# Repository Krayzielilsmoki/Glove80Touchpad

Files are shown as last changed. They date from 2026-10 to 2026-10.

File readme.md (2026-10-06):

# CustomTouchpad V7 🚀

A DIY ergonomic desktop trackpad module powered by QMK & Vial on a Raspberry Pi RP2040 Pro Micro. Features a 40mm Cirque GlidePoint curved trackpad, dual rotary encoders (volume knob + smooth scroll roller), and customizable status RGB lighting.




---

## 📸 Photos & Demo Video

| Physical Build | Assembly / Internal Fit | Wiring Diagram |
| :---: | :---: | :---: |
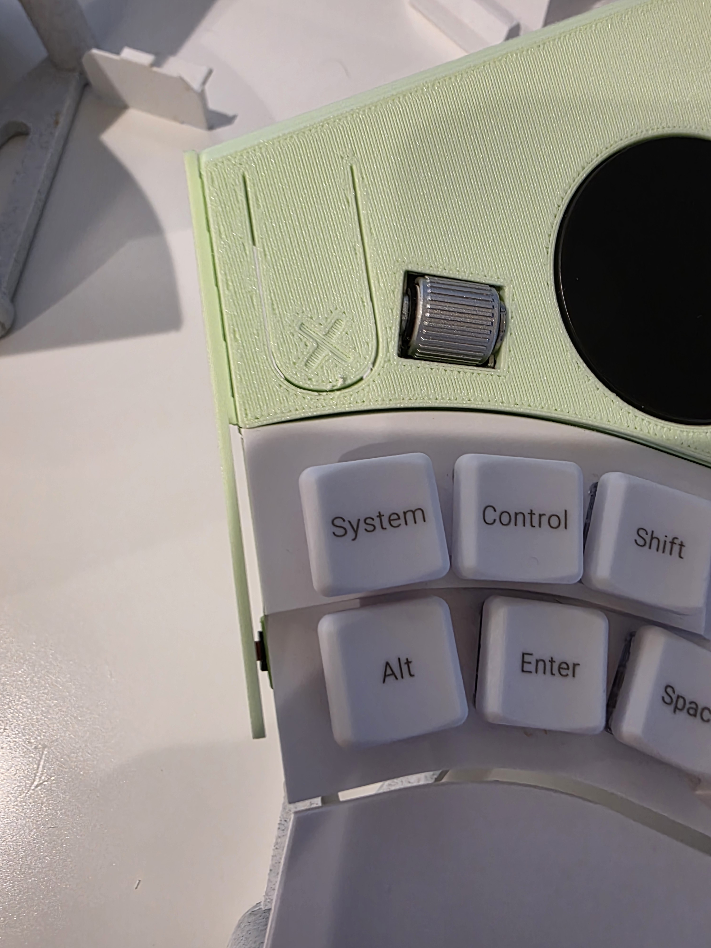
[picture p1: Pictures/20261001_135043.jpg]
Touchpad Top View
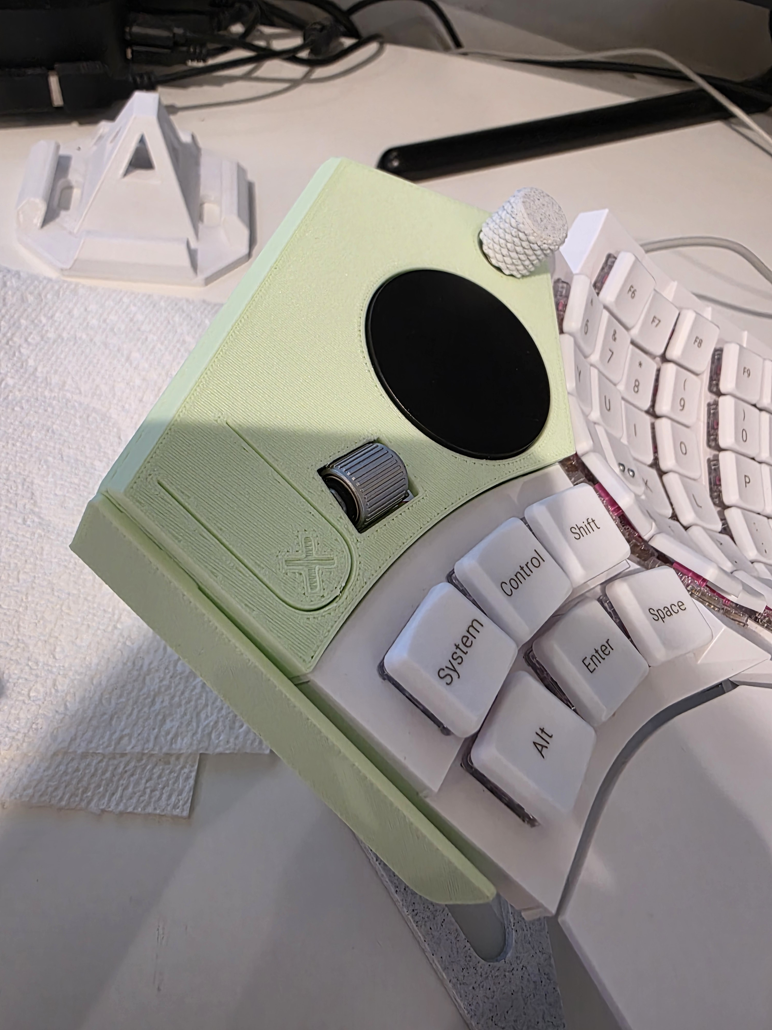
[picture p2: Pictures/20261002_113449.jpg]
Touchpad Build View
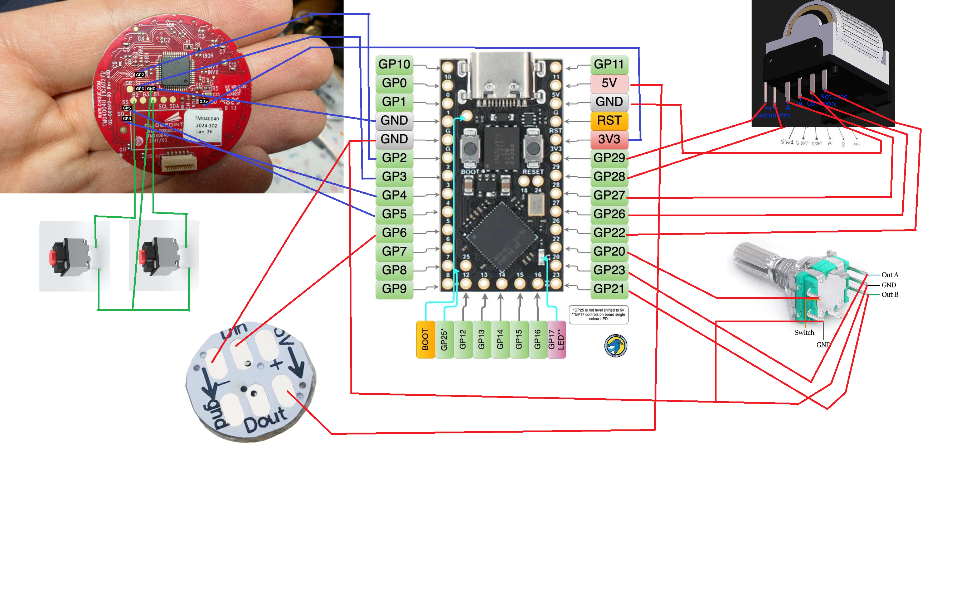
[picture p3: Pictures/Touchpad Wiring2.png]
Touchpad Wiring
|  |  |  |

🎥 **Video Demonstration**: [Watch the short showcase on YouTube](https://youtube.com/shorts/NrFE-3k1rw0)

---

## 🛠 Features

- **Cirque GlidePoint 40mm Curved Trackpad** (`TM040040-2024-303`) via SPI.
  - Dynamic Touchpad Ballistics (variable speed acceleration: slow finger movements give pixel-perfect fine control, fast flicks traverse multi-monitor setups effortlessly).
  - Sub-pixel precision accumulator to prevent pixel jitter.
  - Native Tap-to-Click, Cursor Glide (inertial flick coasting), Circular Edge Scrolling, and hardware smoothing filter.
  - Dedicated hardware mouse buttons (B1 / B2).
- **Dual Encoders**:
  - **EC11 Rotary Encoder**: Smooth audio volume wheel + push-button mute (`KC_MUTE`) on Layer 0; YouTube / media 5-second skip backward/forward + play/pause on Layer 1.
  - **Panasonic EVQWGD001 Roller Encoder**: Precision vertical / horizontal scrolling with customizable acceleration curves.
- **Multifunction Layer & Anti-Sleep Screensaver**:
  - **Layer 0 (Navigation)**: Default desktop trackpad, scroll wheel, volume knob.
  - **Layer 1 (Media / Productivity)**: Horizontal scrolling, video scrubbing (±5s seek), play/pause.
  - **Layer 2 (Anti-Sleep Screensaver / Mouse Jiggler)**: Long-press the roller button (400ms) to engage undetectable, human-like Bezier curve cursor simulation or geometric patterns (Pong bouncer, Orbit, Lissajous).
- **WS2812B RGB Status LED**: Real-time layer indicators, customizable colors, and auto-idle timeout.
- **Full Vial Integration**: Adjust sensitivity (ADC attenuation), CPI (600–1800), acceleration curves, scroll inversion, and LED colors on the fly via [Vial Web](https://vial.rocks/) without reflashing.

---

## 🧰 Bill of Materials (BOM) & Components

### Electronics & Sensors
| Component | Description | Notes |
| :--- | :--- | :--- |
| **RP2040 Pro Micro** | 3.3V RP2040 Microcontroller Board | USB Type-C recommended (sourced from AliExpress/Amazon) |
| **Cirque GlidePoint TM040040** | 40mm Circular Trackpad (Curved Overlay `TM040040-2024-303`) | SPI interface configuration (remove R1 resistor on trackpad to enable SPI mode) |
| **Panasonic EVQWGD001** | Roller Encoder | Used for primary vertical/horizontal scroll wheel (sourced from AliExpress) |
| **EC11 Rotary Encoder** | Incremental encoder with push button | Knob navigation & volume control (AliExpress/Amazon) |
| **WS2812B SMD LED** | 5050 / 3535 Addressable RGB LED | GP6 data line for status illumination |
| **JST Connectors / Pre-crimped Wires** | JST-SH (1.0mm) or JST-XH/ZH (1.25mm/1.5mm) | **Crucial for assembly**: Allows each component to unplug easily, making final fitting inside the tight enclosure possible |
| **Hookup Wire** | 28 AWG to 30 AWG silicone wire | Flexible stranded wire recommended |

> [!TIP]  
> Most electronic components (RP2040 Pro Micro, Cirque trackpad, EVQWGD001 roller, EC11 encoders, and JST connector kits) can be sourced very affordably from **AliExpress**.

### Fasteners, Inserts & Tools
| Hardware | Item / Link | Notes |
| :--- | :--- | :--- |
| **Heat-Set Threaded Inserts** | [M2.5 Heat-Set Brass Inserts (Amazon)](https://www.amazon.com/dp/B0FWCG2K1F?ref=ppx_yo2ov_dt_b_fed_asin_title&th=1) | Installed into 3D-printed standoffs for durable screw fastening (or AliExpress) |
| **Screws & Nuts Assortment** | [Mxuteuk Metric M2/M2.5/M3 Screws & Nuts Kit (Amazon)](https://www.amazon.com/dp/B0G8F366MV?ref=ppx_yo2ov_dt_b_fed_asin_title&th=1) | M2.5 socket head cap screws used for assembling top and bottom case |
| **Soldering Iron** | [80W Digital Soldering Iron Kit (Amazon)](https://www.amazon.com/dp/B08R3515SF?ref=ppx_yo2ov_dt_b_fed_asin_title&th=1) | Budget adjustable-temp iron suitable for wiring and heat-setting inserts |
| **Allen / Hex Key** | Standard small M2.5 hex wrench (included with screw kit) | Used for driving screws and reaming undersized holes |

---

## 🔌 Pinout & Wiring Diagram

Refer to the wiring schematic in [`Pictures/Touchpad Wiring2.png`](Pictures/Touchpad%20Wiring2.png):

| Component | Pin Function | RP2040 Pro Micro Pin |
| :--- | :--- | :--- |
| **Cirque Trackpad (SPI)** | SCK (Clock) | **GP2** |
| | MOSI (Data In) | **GP3** |
| | MISO (Data Out) | **GP4** |
| | CS (Chip Select) | **GP5** |
| | VCC | **3.3V** |
| | GND | **GND** |
| **Status RGB LED** | DI (Data In) | **GP6** |
| | 5V / VCC & GND | **VBUS (or 3.3V)** & **GND** |
| **Push-Button Switches** | EC11 Button Push | **GP20** (Row 0, Col 0 - Active Low) |
| | Roller Button Push | **GP29** (Row 0, Col 1 - Active Low) |
| **EC11 Rotary Encoder** | Phase A | **GP21** |
| | Phase B | **GP23** |
| | Common Pin | **GND** |
| **Panasonic EVQWGD001 Roller** | Phase A | **GP27** |
| | Phase B | **GP26** |
| | Common Pin | **GND** |

> [!NOTE]  
> The buttons are configured as direct matrix pins (`GP20`, `GP29`). Ensure switches connect between their designated GPIO pin and Ground (`COL2ROW` internal pull-up logic).

---

## 🖨️ 3D Printing & Enclosure Assembly

All enclosure STL models are located in the [`3d Print Files/`](3d%20Print%20Files/) folder:

- `top v3.stl`: Top shell housing the trackpad and encoder openings.
- `Bottom v5.stl`: Base enclosure holding the microcontroller, roller, and wiring.
- `Bottom Cover v1.stl`: Bottom access plate.
- `Clicker v3.stl`: Internal mechanical button lever / pivot.
- `keeper piece.stl`: Retaining bracket for the trackpad/roller assembly.
- `MyKnob.stl`: Custom tactile knob for the EC11 rotary encoder.

### 💡 3D Printing & Assembly Tips:
1. **Undersized Holes (Printer Tolerance)**:  
   The screw holes in the 3D printed files were intentionally modeled slightly undersized to account for different printer tolerances and shrinkage. **You can easily clear / enlarge them to the perfect diameter simply by running through them with the small Allen hex key used for the M2.5 screws.**
2. **Heat-Set Insert Installation**:  
   Set your soldering iron to ~220–250°C (if printing in PLA/PETG). Place an M2.5 brass heat-set insert over each mounting hole, gently press down with the tip of the soldering iron until the insert sinks flush with the plastic rim, then remove the iron and let it cool without disturbing it.
3. **Modular JST Connectors (Crucial for Assembly)**:  
   Because the custom enclosure is compact and tightly integrated, soldering all components directly to the RP2040 board with permanent wires makes mechanical assembly nearly impossible. **Using JST connectors (or pre-crimped JST pigtails) allows each module—trackpad, encoders, LED, and buttons—to be unplugged during installation and snapped together inside the case.**

---

## 💾 Firmware & Flashing

A pre-compiled, ready-to-flash Vial firmware binary is included right in this directory:
📁 **[`custom_touchpad_v7_vial.uf2`](custom_touchpad_v7_vial.uf2)**

### Flashing Instructions:
1. Hold down the **BOOT** button on the RP2040 Pro Micro board and plug it into your computer via USB (or double-tap **RESET**).
2. The board will appear as a removable USB storage drive named `RPI-RP2`.
3. Drag and drop [`custom_touchpad_v7_vial.uf2`](custom_touchpad_v7_vial.uf2) onto the `RPI-RP2` drive.
4. The board will automatically reboot as an HID trackpad and keyboard device.
5. Open [Vial Web App](https://vial.rocks/) or the Vial desktop application in Chrome / Edge to configure layers, sensitivity curves, and RGB settings in real time!

### Compiling from Source (Optional)
If you want to modify keymaps or compile from source within this repository:
```bash
make handwired/bojan/custom_touchpad_v7:vial
```

---

## 🎮 Default Controls & Gestures

### Layer 0: Standard Navigation (Default)
- **Trackpad**: Cursor movement (dynamic velocity acceleration).
- **Single Tap**: Left Click.
- **Top-Right / Outer Perimeter**: Circular Scroll (or roller wheel).
- **EC11 Knob Rotate**: Volume Down / Volume Up.
- **EC11 Knob Click**: Audio Mute / Unmute.
- **EVQWGD001 Roller Scroll**: Accelerated Vertical Page Scroll.
- **EVQWGD001 Roller Click**: 
  - *Short Tap*: Switch between Layer 0 and Layer 1.
  - *Hold (>= 400ms)*: Enter Layer 2 (Anti-Sleep Screensaver).

### Layer 1: Media & Productivity
- **EC11 Knob Rotate**: YouTube / Video seek 5s backward (`KC_LEFT`) / forward (`KC_RIGHT`).
- **EC11 Knob Click**: Play / Pause video (`KC_MPLY`).
- **EVQWGD001 Roller Scroll**: Horizontal scroll (`MS_WHLL` / `MS_WHLR`).
- **EVQWGD001 Roller Click**: Switch back to Layer 0.

### Layer 2: Screensaver / Anti-Sleep Mode
- **EC11 Knob Rotate**: Increase / decrease movement speed (1–10).
- **EVQWGD001 Roller Scroll**: Cycle through 4 animation patterns:
  - *Pattern 0*: Natural Human Simulator (random idle pauses & smooth Bezier curves).
  - *Pattern 1*: Pong / DVD screen bounce.
  - *Pattern 2*: Circular orbit.
  - *Pattern 3*: Lissajous figure-8.
- **Any Button Click or Trackpad Movement**: Automatically wakes and returns to Layer 0.

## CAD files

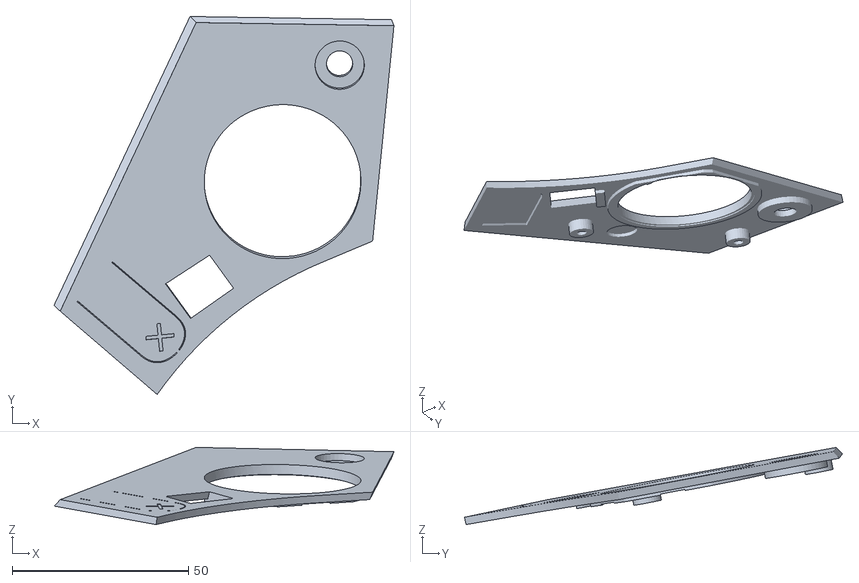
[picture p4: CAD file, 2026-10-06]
3d Print Files/top v3.stl
96.5 x 107.3 x 21.9

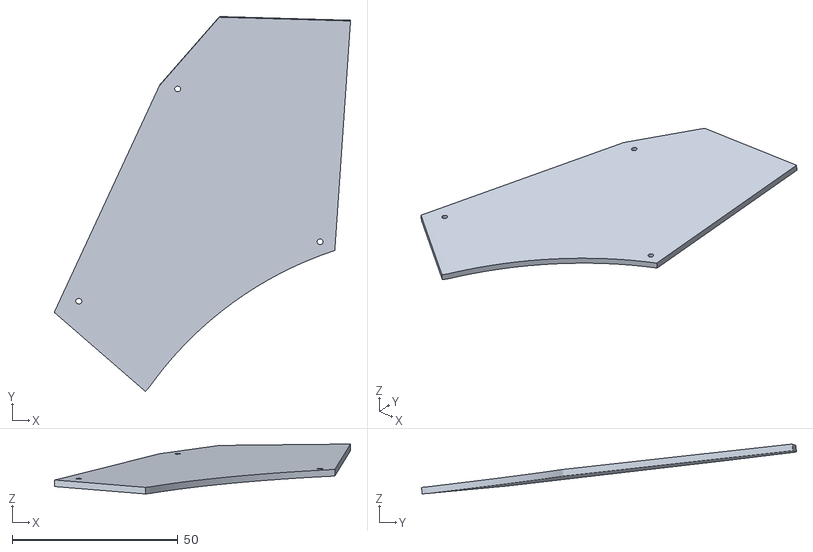
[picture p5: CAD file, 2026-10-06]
3d Print Files/Bottom Cover v1.stl
89.3 x 113.1 x 15.1

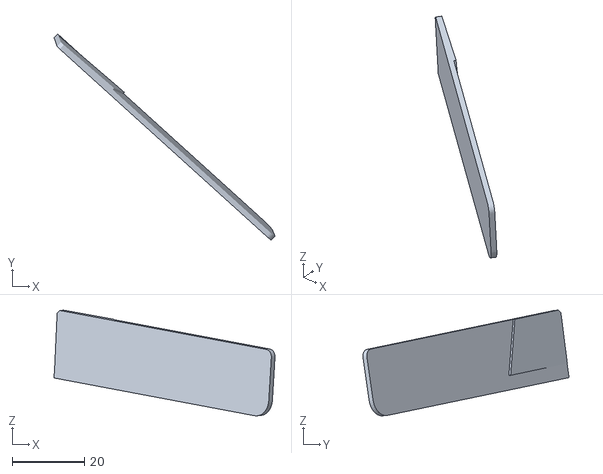
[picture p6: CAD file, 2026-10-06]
3d Print Files/Clicker v3.stl
61.2 x 57.1 x 29.3

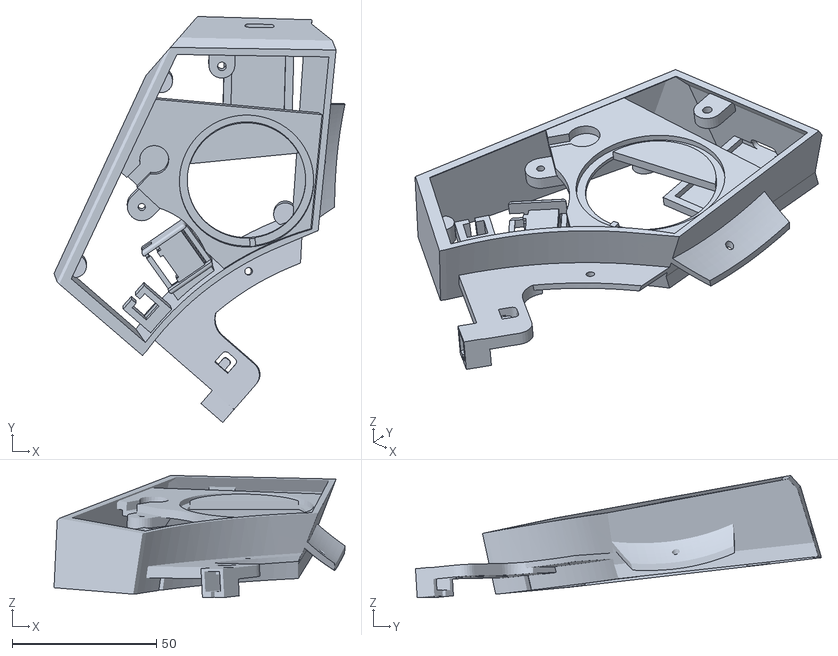
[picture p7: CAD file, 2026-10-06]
3d Print Files/Bottom v5.stl
100.8 x 140.6 x 42.3

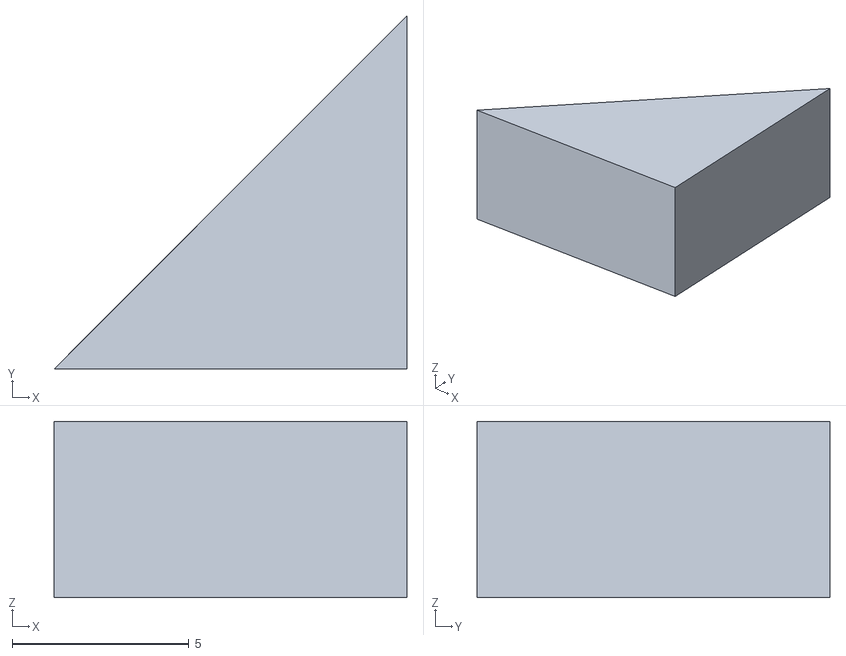
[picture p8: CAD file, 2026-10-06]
3d Print Files/keeper piece.stl
10.00 x 10.0 x 5.00

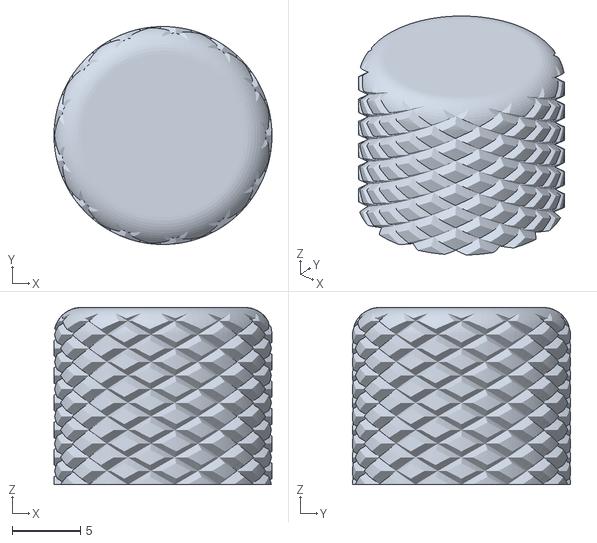
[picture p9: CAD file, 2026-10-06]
3d Print Files/MyKnob.stl
16.0 x 16.0 x 13.0

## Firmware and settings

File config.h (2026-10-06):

#pragma once

// ==========================================
// 1. SPI PIN ASSIGNMENTS (Cirque Trackpad)
// ==========================================
#define SPI_SCK_PIN GP2
#define SPI_MOSI_PIN GP3
#define SPI_MISO_PIN GP4
#define POINTING_DEVICE_CS_PIN GP5

// ==========================================
// 2. CIRQUE TRACKPAD CONFIGURATION
// ==========================================
#define CIRQUE_PINNACLE_DIAMETER_MM 40
#define POINTING_DEVICE_ROTATION_270
#define CIRQUE_PINNACLE_TAP_ENABLE
#define CIRQUE_PINNACLE_CIRCULAR_SCROLL_ENABLE

// Curved Overlay (TM040040-2024-303) tuning & sensitivity
#define CIRQUE_PINNACLE_CURVED_OVERLAY
#define CIRQUE_PINNACLE_ATTENUATION EXTREG__TRACK_ADCCONFIG__ADC_ATTENUATE_2X

#define POINTING_DEVICE_INVERT_Y
#define POINTING_DEVICE_INVERT_X

// Inertial cursor flick (glide across screen)
#define POINTING_DEVICE_GESTURES_CURSOR_GLIDE_ENABLE

// Extended 16-bit mouse reports for smooth, high-speed movement
#define MOUSE_EXTENDED_REPORT

// ==========================================
// 3. WS2812 RGB STATUS LED CONFIGURATION
// ==========================================
#define WS2812_DI_PIN GP6
#define WS2812_LED_COUNT 1
#define WS2812_BYTE_ORDER WS2812_BYTE_ORDER_GRB

// VIA layout options EEPROM configuration
// 4 bytes for all V7 touchpad ballistics, precision mode, scroll acceleration, LED, and screensaver options
#define VIA_EEPROM_LAYOUT_OPTIONS_SIZE 4
#define VIA_EEPROM_LAYOUT_OPTIONS_DEFAULT 0x025D2600

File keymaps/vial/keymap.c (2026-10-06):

#include QMK_KEYBOARD_H
#include <math.h>
#include <stdlib.h>
#include "ws2812.h"
#include "via.h"

// Forward declarations for Cirque runtime API (defined in drivers/sensors/cirque_pinnacle*.c)
// These are not in the keymap include path but are resolved at link time.
void cirque_pinnacle_enable_circular_scroll(bool enable);
void cirque_pinnacle_configure_circular_scroll(uint8_t outer_ring_pct, uint8_t trigger_px, uint16_t trigger_ang, uint8_t wheel_clicks, bool left_handed);
bool cirque_pinnacle_set_adc_attenuation(uint8_t adcGain);
void cirque_pinnacle_enable_feed(bool feedEnable);
void cirque_pinnacle_enable_tap(bool enable);
void cirque_pinnacle_enable_cursor_glide(bool enable);
void cirque_pinnacle_cursor_smoothing(bool enable);
void cirque_pinnacle_set_cpi(uint16_t cpi);

#ifndef M_PI
#    define M_PI 3.14159265358979323846f
#endif

// ==========================================
// 1. LAYER ENUMERATIONS
// ==========================================
enum layers {
    _LAYER_0 = 0, // Default: Navigation / Standard Mouse & Encoders
    _LAYER_1,     // Media & Productivity (LED: User-selected color)
    _LAYER_2,     // Screensaver / Anti-Sleep Mode (LED: Rainbow Color Fade)
    _LAYER_3      // Transparent / Expansion
};

// ==========================================
// 2. CUSTOM KEYCODES
// ==========================================
enum custom_keycodes {
    SW_LAYER = SAFE_RANGE, // Roller Button: Tap -> Layer 0/1 Toggle, Long Press -> Screensaver (Layer 2)
    SCRN_SPD_DN,           // Layer 2: Decrease screensaver speed
    SCRN_SPD_UP,           // Layer 2: Increase screensaver speed
    SCRN_PAT_PREV,         // Layer 2: Previous screensaver animation pattern
    SCRN_PAT_NEXT,         // Layer 2: Next screensaver animation pattern
    TP_CIRC_TOG,           // User keycode: Toggle circular scroll on/off
    TP_SENS_CYC,           // User keycode: Cycle sensitivity (Level 1 -> 2 -> 3 -> 4)
    SCRN_TOG               // User keycode: Toggle screensaver mode
};

// ==========================================
// 3. VIAL LAYOUT OPTIONS & HARDWARE STATE
// ==========================================
// Sensitivity levels (ADC attenuation) — reversed so higher level = more sensitive:
//   index 0 = 4X attenuation (least sensitive)
//   index 1 = 3X attenuation
//   index 2 = 2X attenuation  ← default
//   index 3 = 1X attenuation  (most sensitive, no attenuation)
static const uint8_t sens_adc_values[] = { 0xC0, 0x80, 0x40, 0x00 };
#define NUM_SENS_LEVELS 4

// CPI / Pointer speed presets
static const uint16_t cpi_presets[] = { 600, 800, 1000, 1400, 1800 };
#define NUM_CPI_PRESETS 5

// Auto-Idle timeout options (in milliseconds)
static const uint32_t timeout_presets_ms[] = { 0, 60000, 180000, 300000, 600000 };

// Layer 1 LED color presets (R, G, B)
typedef struct {
    uint8_t r;
    uint8_t g;
    uint8_t b;
} led_color_t;

static const led_color_t layer1_colors[] = {
    {  0,   0,  60 }, // 0: Solid Blue (Default)
    {  0,  45,  45 }, // 1: Cyan
    {  0,  60,   0 }, // 2: Green
    { 50,   0,  50 }, // 3: Magenta / Purple
    { 40,  40,   0 }, // 4: Yellow
    { 60,  20,   0 }, // 5: Orange
    { 60,   0,   0 }, // 6: Red
    { 35,  35,  35 }, // 7: White
    {  0,   0,   0 }  // 8: LED Off
};
#define NUM_LED_COLORS 9

// Runtime configurable settings (bound to Vial Layouts tab)
static bool    tp_circ_scroll       = false; // Circular scroll enable (bit 26)
static uint8_t tp_sens_index        = 2;     // Sensitivity: Level 3 (2X default) (bits 24..25)
static uint8_t tp_cpi_index         = 2;     // CPI: 1000 CPI default (bits 21..23)
static bool    tp_smoothing         = true;  // Hardware smoothing filter (bit 20)
static bool    tp_tap_enable        = true;  // Tap-to-click (bit 19)
static bool    tp_glide_enable      = true;  // Cursor glide / inertial coasting (bit 18)
static uint8_t tp_accel_level       = 2;     // Touchpad acceleration curve (bits 15..17: 0=Linear, 1=Mild 2x, 2=Balanced 3.5x, 3=Aggressive 5x, 4=Ultra 7x)
static uint8_t tp_prec_mode         = 1;     // Touchpad precision mode (bits 13..14: 0=1.0x, 1=0.75x slow, 2=0.50x slow)
static bool    tp_circ_scroll_dir   = false; // Circular scroll direction (0=Down, 1=Up) (bit 12)
static uint8_t tp_circ_ring_width   = 1;     // Ring width (0=15%, 1=25%, 2=35%) (bits 10..11)
static uint8_t roller_accel_level   = 2;     // Scroll wheel acceleration (bits 8..9: 0=Linear, 1=Mild 4x, 2=Std 8x, 3=Aggressive 12x)
static bool    roller_invert_dir    = false; // Invert scroll wheel direction (bit 7)
static uint8_t auto_idle_timeout_idx= 0;     // Screensaver auto-idle timeout index (bits 4..6)
static uint8_t layer1_color_idx     = 0;     // Layer 1 LED color index (bits 0..3)

static uint32_t last_activity_time  = 0;     // Timestamp of last user movement/click

static void touchpad_apply(void) {
    cirque_pinnacle_enable_circular_scroll(tp_circ_scroll);

    uint8_t ring_pct = (tp_circ_ring_width == 0) ? 15 : ((tp_circ_ring_width == 1) ? 25 : 35);
    cirque_pinnacle_configure_circular_scroll(ring_pct, 10, 8192, 100, tp_circ_scroll_dir);

    cirque_pinnacle_set_adc_attenuation(sens_adc_values[tp_sens_index]);
    cirque_pinnacle_set_cpi(cpi_presets[tp_cpi_index]);
    cirque_pinnacle_cursor_smoothing(tp_smoothing);
    cirque_pinnacle_enable_tap(tp_tap_enable);
    cirque_pinnacle_enable_cursor_glide(tp_glide_enable);
    cirque_pinnacle_enable_feed(true);
}
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
